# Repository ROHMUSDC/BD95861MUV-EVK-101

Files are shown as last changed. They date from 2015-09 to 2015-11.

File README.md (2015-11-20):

# BD95861MUV-EVK-101 Design Resource Repository
* Hardware Design Files and Documentation for the ROHM BD95861MUV-EVK-101 EVK

----
### Description: 
* BD95861MUV is a 1ch synchronous buck converter that can generate output voltage (0.8V to 5.5V) at the input voltage range (7.5V to 18V)
* Space-saving and high efficient switching regulator can be achieved due to built-in N-MOSFET power transistors
* The IC also incorporates H3 RegTM technology, a Rohm proprietary constant ON TIME control mode which facilitates ultra-high transient response against changes in load without external compensation components
* Fixed soft start function, power good function, and short circuit/over voltage protection with timer latch functions are incorporated
* The BD95861MUV is designed for power supplies for Digital AV Equipment

----
### Repository Contents
* Application Note Folder: Contains Draft Version of EVK Application Note
* Design Files: Contains Board, Gerber, Schematic, and BOM information for this EVK Board
* Measurement Reports Folder: Contains measurement testing information completed for these EVK Boards

----
### Where to Purchase?
* http://www.rohm.com/web/global/distribution/-/dinventory/BD95861MUV-EVK-101/sample/0

----
### DISCLAIMER
This Technical Data is protected under copyright laws.

ROHM hereby grants you a nonexclusive, nontransferable license to use this Technical Data 
as long as you abide by the terms and conditions of this DISCLAIMER. 

However, you are not authorized to sell, loan, rent, lease, redistribute or license this Technical Data, 
in whole or in part, or in modified form, to anyone.

You may modify this Technical Data to suit your specific applications, 
but the rights to derivative works and said modifications shall belong to ROHM. 

You may make copies of this Technical Data as necessary for internal use only within your company.

In any case, the latest datasheet is considered the final design guideline and represents 
the only actual performance specifications.

ROHM shall not be responsible for ensuring proper application on all computer systems.
This Technical Data is provided AS IS. ROHM makes no guarantees, either implicitly or explicitly, 
regarding its usability, functionality, accuracy, merchantability, or fitness for a specific purpose.

In addition, you shall take full responsibility for the use of any information acquired from this Technical Data. 

ROHM does not assume warranty of any kind arising from the use of this Technical Data. ACCORDINGLY, 
IN NO EVENT SHALL ROHM BE RESPONSIBLE, WHETHER THROUGH CONTRACT OR TORT LIABILITY, 
FOR ANY DAMAGES (INCLUDING BUT NOT LIMITED TO LOST PROFITS OR OTHER INCIDENTAL, CONSEQUENTAL, 
OR PUNITIVE DAMAGES) ARISING OUT OF OR IN CONNECTION WITH THE USE OR APPLICATION OF THIS Technical Data.

Furthermore, this Technical Data is subject to change without notice.

Unless otherwise expressly provided herein, ROHM does not convey any license under patent rights 
or any other intellectual property rights (including those of third parties).

ROHM is not obligated to provide maintenance or support for the Technical Data.

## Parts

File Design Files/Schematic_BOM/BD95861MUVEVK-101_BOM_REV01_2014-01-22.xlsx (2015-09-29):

ROHM - TITLE & REVISION HISTORY Revised: Tuesday, January 07, 2014
xxxx Revision: 01
Bill Of Materials January 7,2014 10:31:23 | Page1
Item | Quantity | Reference | Part | PCB Footprint | DESCRIPTION | MANUFACTURER1 | MANUFACTURER1_PART# | DISTR1 | DISTR1_PART# | DNP
______________________________________________
1 | 1 | CR1 | SML-310MTT86 | LED_0603 | LED 570NM GREEN WTR CLR 0603 SMD | Rohm | SML-310MTT86 | DIGIKEY | 511-1299-1-ND
2 | 2 | C1,C2 | 10uF | C1206 | CAP CER 10UF 25V 20% X5R 1206 | Murata | GRM31CR61E106MA12L | DIGIKEY | 490-5423-1-ND
3 | 1 | C3 | 0.1uF | C0603 | CAP CER 0.1UF 50V 10% X7R 0603 | Murata | GRM188R71H104KA93D | DIGIKEY | 490-1519-1-ND
4 | 2 | C4,C5 | 22uF | C1206 | CAP CER 22UF 16V 10% X5R 1206 | Murata | GRM31CR61C226KE15K | DIGIKEY | 490-6512-1-ND
5 | 1 | C6 | 4.7uF | C0603 | CAP CER 4.7UF 25V 10% X5R 0603 | Murata | GRM188R61E475KE11D | DIGIKEY | 490-7203-1-ND
6 | 1 | C7 | 0.47uF | C0603 | CAP CER 0.47UF 25V 10% X7R 0603 | Murata | GRM188R71E474KA12D | DIGIKEY | 490-3291-2-ND
7 | 1 | C8 |  | C1206 |  |  |  |  |  | DNP( Do not place)
8 | 1 | C9 |  | C0805 |  |  |  |  |  | DNP( Do not place)
9 | 1 | D1 | SMAJ15A | DO-214AC | DIODE TVS 15V 400W UNI 5% SMA | Littelfuse Inc | SMAJ15A | DIGIKEY | SMAJ15ALFTR-ND
10 | 2 | D2,D3 | RB085B-30TL | CPD | DIODE SCHOTTKY 30V 10A CPD | Rohm | RB085B-30TL | DIGIKEY | RB085B-30TLCT-ND | DNP( Do not place)
11 | 1 | J1 | 87224-3 | HDR_THVT_1X3_100 | CONN HEADER VERT .100 3POS 15AU | TE Connectivity Div | 87224-3 | DIGIKEY | A26545-ND
12 | 1 | L1 | 2.2uH | SMT_7P1X6P5 | INDUCTOR 2.2UH 8.2A 20% SMD | TDK Corporation | SPM6530T-2R2M | DIGIKEY | 445-4118-1-ND
13 | 1 | Q1 | SST2222AT116 | SOT23_BEC | TRANSISTOR NPN 40V 0.6A SOT-23 | Rohm | SST2222AT116 | DIGIKEY | SST2222AT116TR-ND
14 | 1 | R1 | 20 | R0603 | RES 20 OHM 1/10W 5% 0603 SMD | Rohm | MCR03ERTJ200 | DIGIKEY | RHM20CGTR-ND
15 | 1 | R2 | 24K | R0603 | RES 24K OHM 1/10W 1% 0603 SMD | Rohm | MCR03ERTF2402 | DIGIKEY | RHM24KCFDKR-ND
16 | 1 | R3 | 680 | R0603 | RES 680 OHM 1/10W 1% 0603 SMD | Rohm | MCR03ERTF6800 | DIGIKEY | RHM680CFTR-ND
17 | 1 | R4 | 4.7K | R0603 | RES 4.7K OHM 1/10W 1% 0603 SMD | Rohm | MCR03ERTF4701 | DIGIKEY | RHM4.70KCFTR-ND
18 | 1 | R5 | 100K | R0603 | RES 100K OHM 1/10W 5% 0603 SMD | Rohm | MCR03ERTJ104 | DIGIKEY | RHM100KCGTR-ND
19 | 1 | R6 | 1K | R0603 | RES 1K OHM 1/10W 5% 0603 SMD | Rohm | MCR03ERTJ102 | DIGIKEY | RHM1.0KCGTR-ND
20 | 1 | R7 | 140 | R0603 | RES 140 OHM 1/10W 1% 0603 SMD | Rohm | MCR03ERTF1400 | DIGIKEY | RHM140CFTR-ND
21 | 3 | TP1,TP2,TP5 | TP_63Mil_TH | TP_TH | TEST POINT PC MULTI PURPOSE RED | Keystone Electronics | 5010 | DIGIKEY | 5010K-ND
22 | 2 | TP3,TP4 | TP_63Mil_TH | TP_TH | TEST POINT PC MULTI PURPOSE BLK | Keystone Electronics | 5011 | DIGIKEY | 5011K-ND
23 | 1 | U1 | BD95861MUV | VQFN024V4040 | 7.5V to 18V, 6A Integrated MOSFET 1ch Synchronous Buck DC/DC Converter | ROHM | BD95861MUV
24 | 1 | ZX1 | 0 | SM_180x060 | 1806 footprint solder-short during assembly
25 | 1 |  |  |  | Shunt jumper for header J1 (item #11), CONN SHUNT 2POS GOLD W/HANDLE | TE Connectivity | 881545-1 | DIGIKEY | 881545-1-ND

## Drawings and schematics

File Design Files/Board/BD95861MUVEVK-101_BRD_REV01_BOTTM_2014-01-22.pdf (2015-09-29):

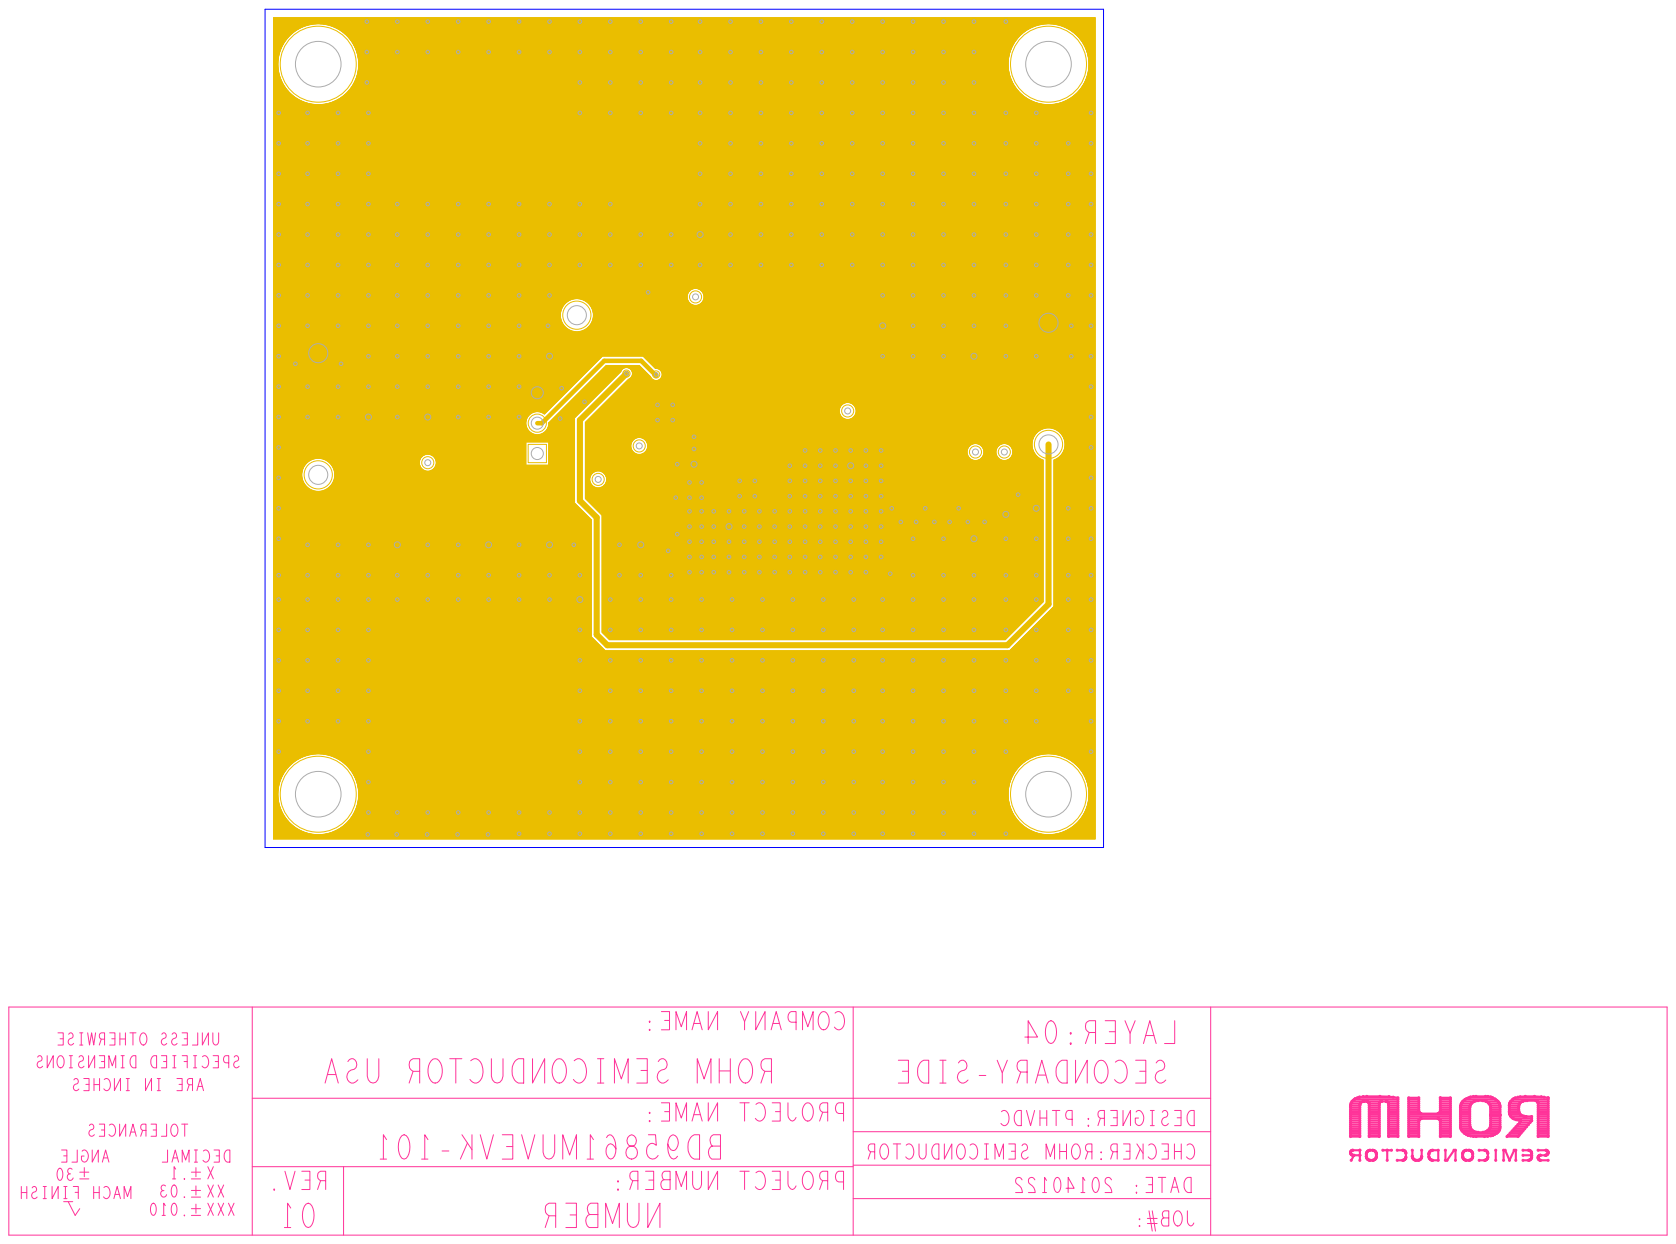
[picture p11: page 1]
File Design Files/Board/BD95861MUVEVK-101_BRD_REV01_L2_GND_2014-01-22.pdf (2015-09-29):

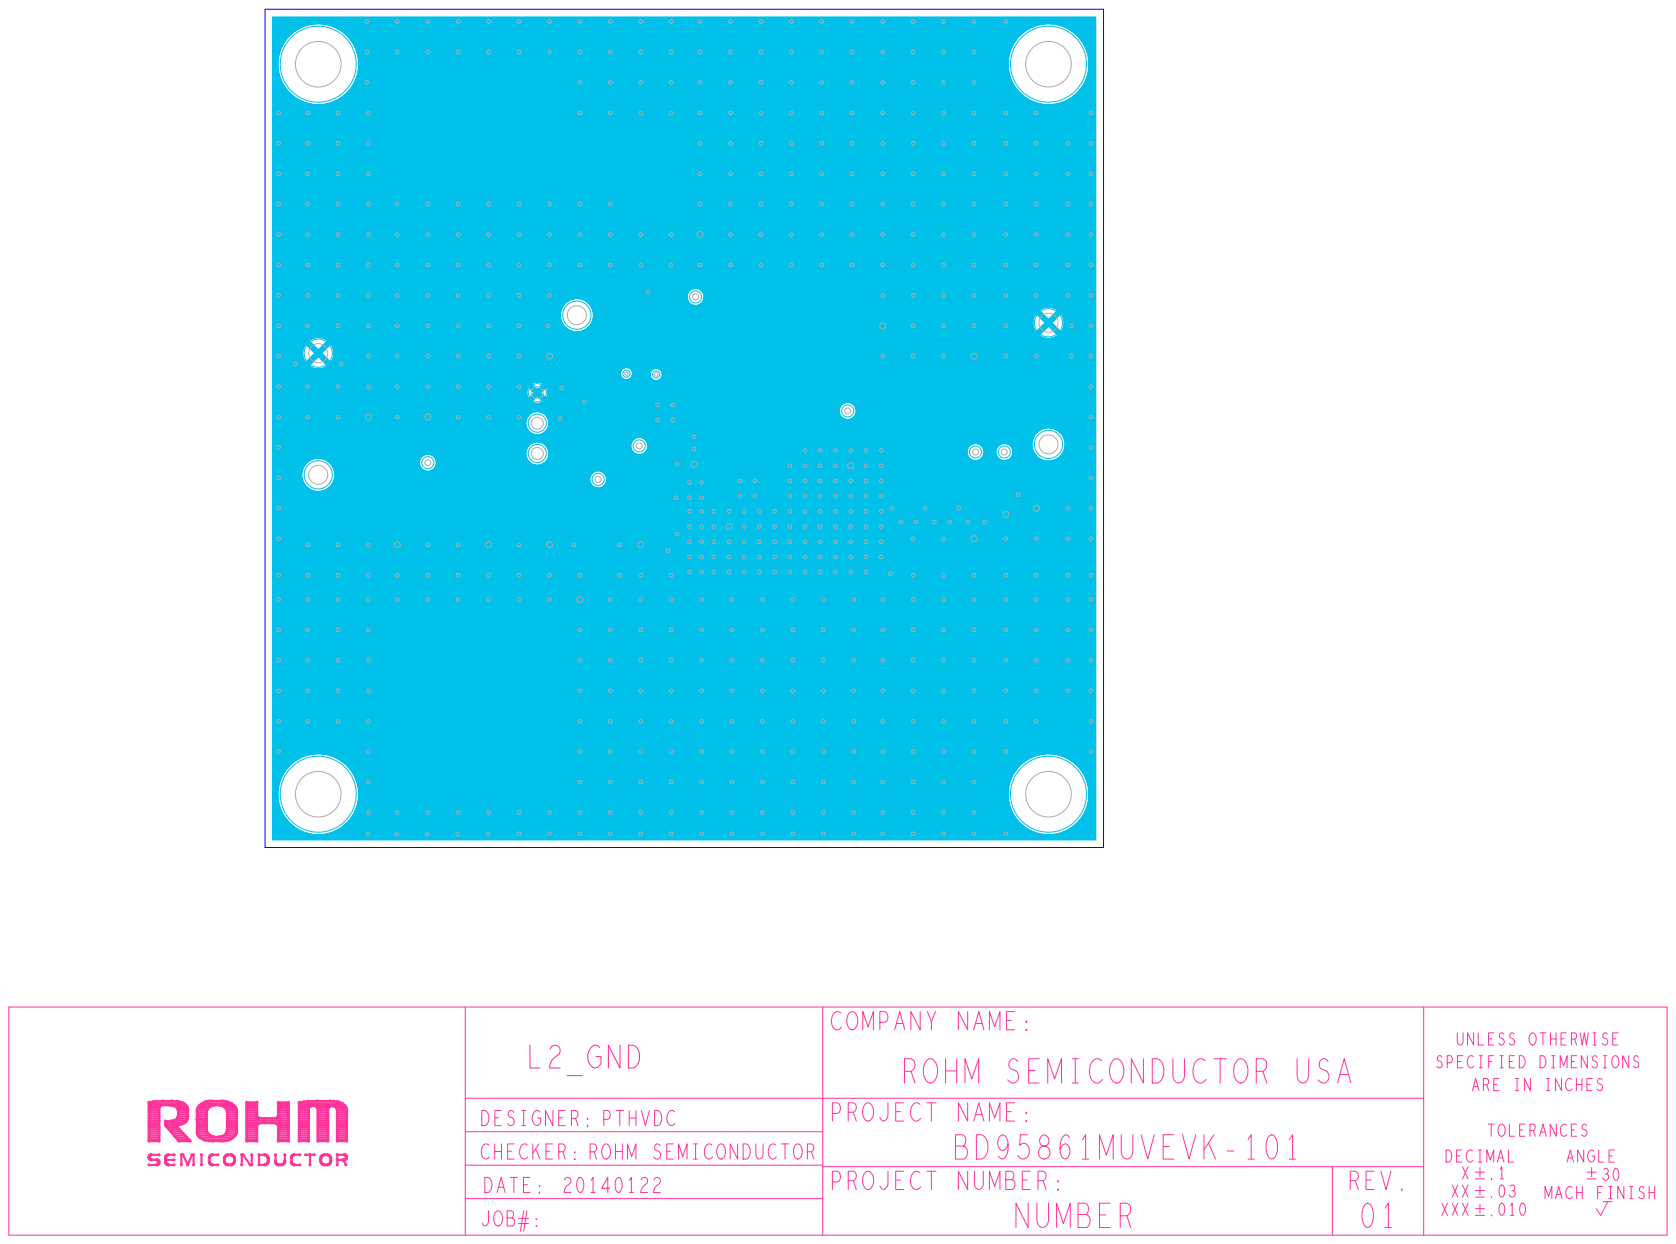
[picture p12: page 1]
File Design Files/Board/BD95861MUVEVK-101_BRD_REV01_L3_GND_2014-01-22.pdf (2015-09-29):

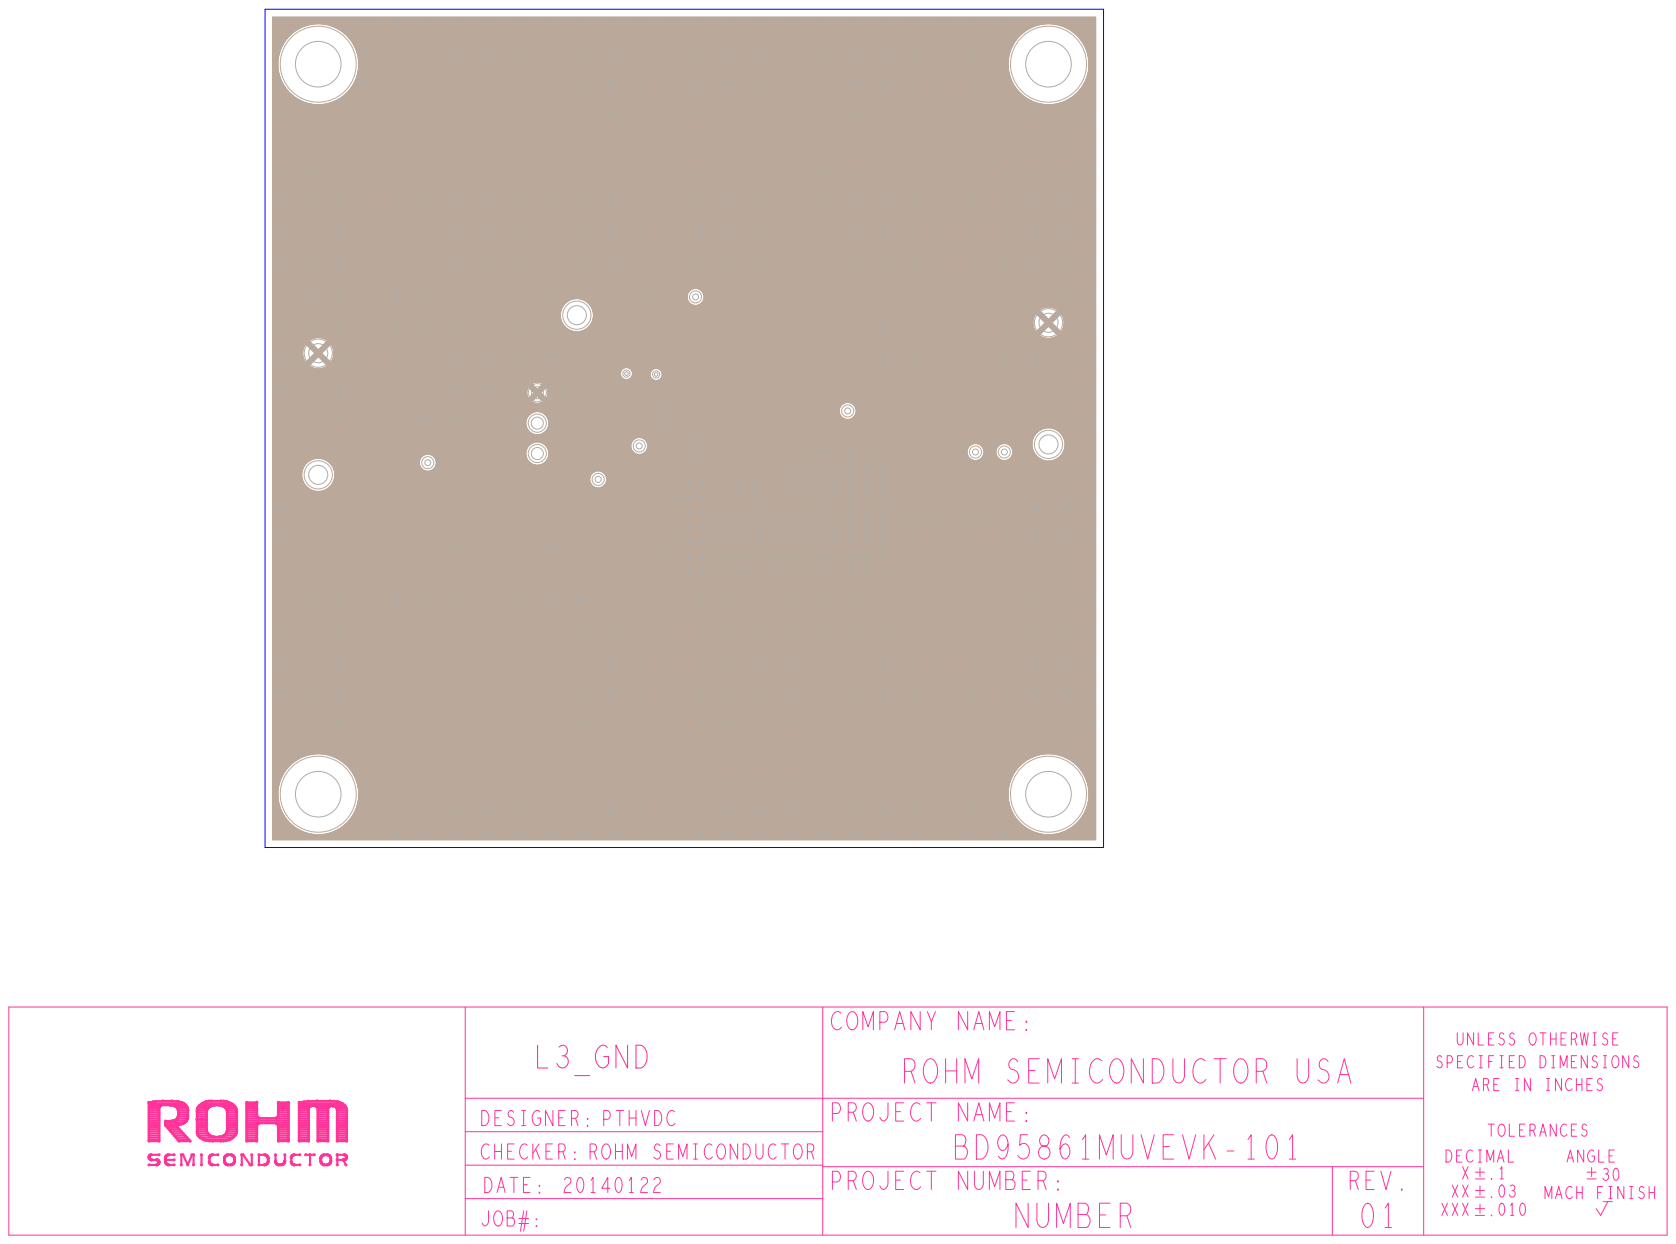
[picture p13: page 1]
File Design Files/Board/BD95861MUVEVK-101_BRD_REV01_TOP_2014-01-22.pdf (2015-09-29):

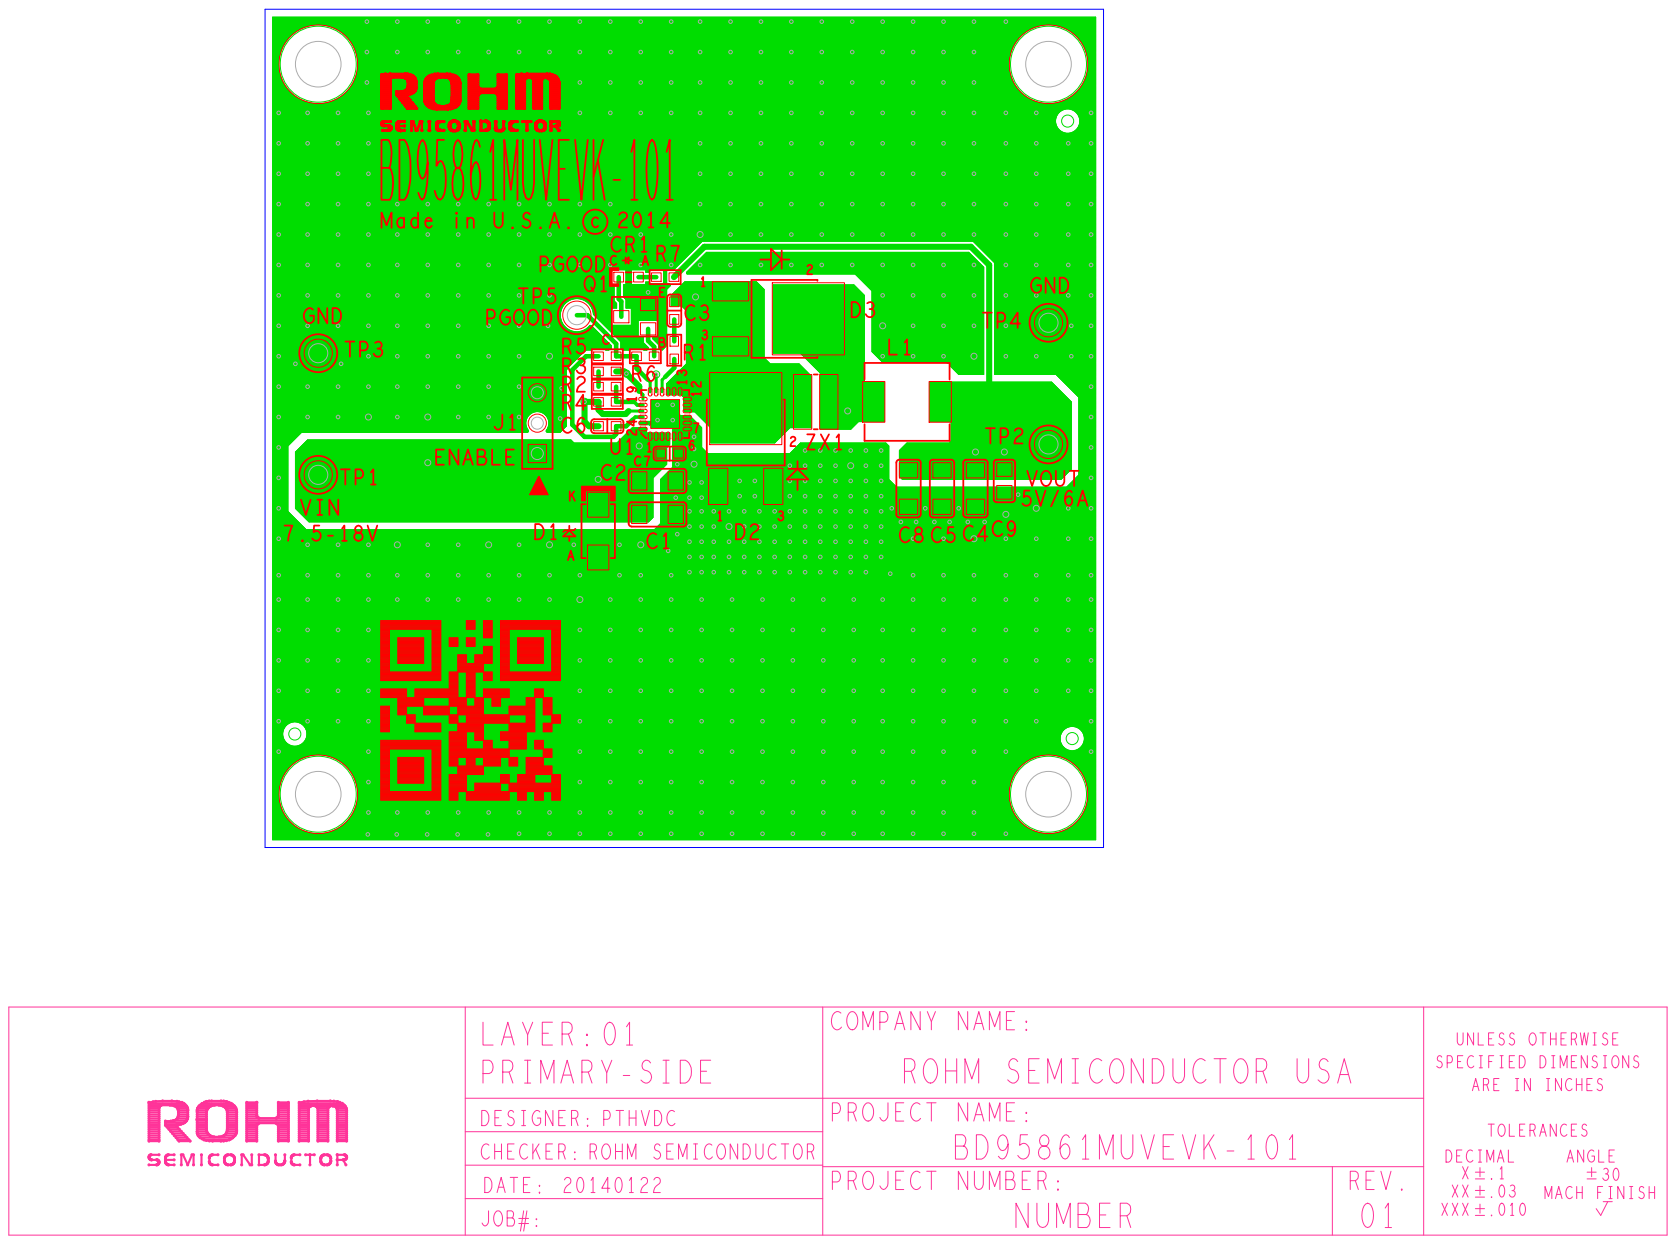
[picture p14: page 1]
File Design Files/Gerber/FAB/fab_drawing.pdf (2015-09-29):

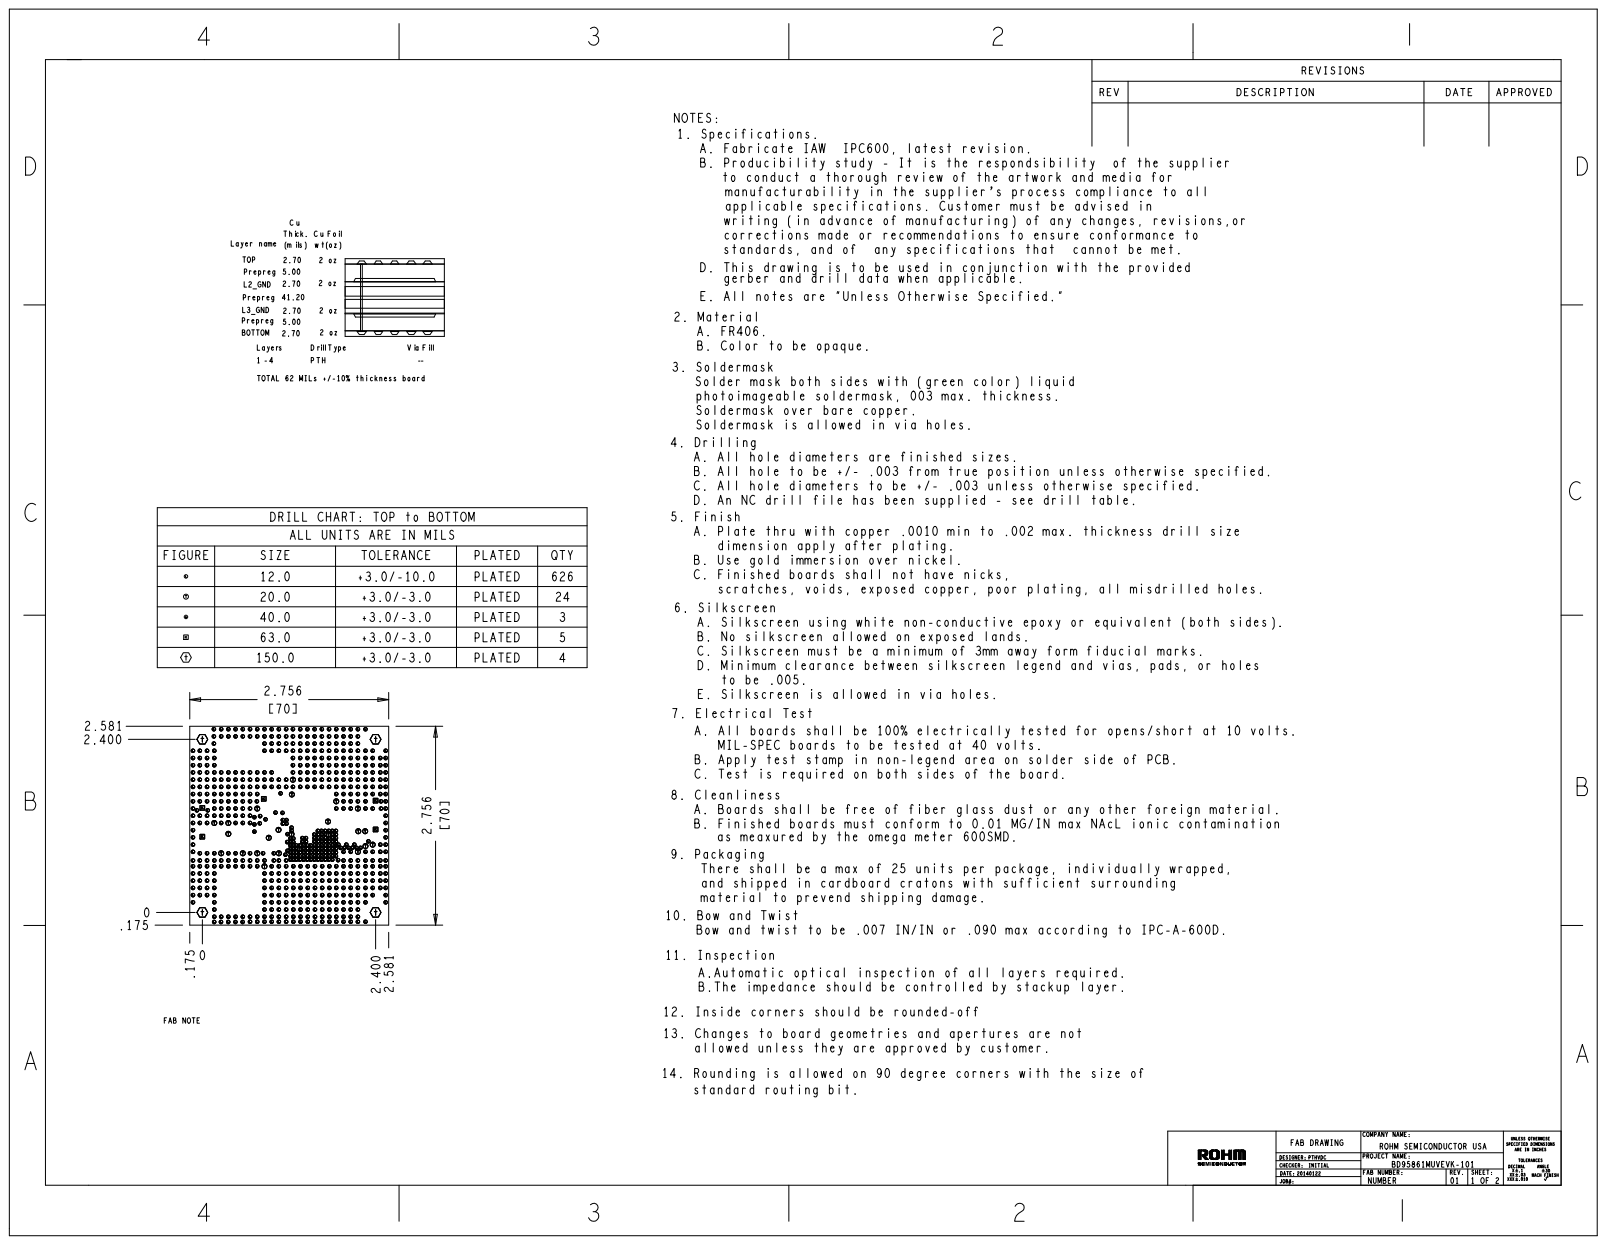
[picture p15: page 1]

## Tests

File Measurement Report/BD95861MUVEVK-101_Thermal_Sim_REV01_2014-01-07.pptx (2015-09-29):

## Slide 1

PI and Thermal Simulation Study for BD95861MUV Board
January 07th, 2014
Hosted by: Xuan Dang

PTH Solutions Confidential

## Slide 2

Agenda
  I. Introduction
  II. DC Drop Analysis
  III. Current Density Analysis
  IV. Thermal Analysis
  V. Conclusion

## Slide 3

Introduction

1. This work considers power simulation and thermal simulation on BD95861MUV boards.
  - Based on board file BD95861MUVEVK-101_EVAL_BRD_REV02_20140107_1800.brd
2. Hyperlynx v8.2.1 and Hyperlynx Thermal v9.1 (MentorGraphic) software is used for simulation
3. PI simulation considers:
  a. DC Drop analysis
    - Determine what the max drop for power rail
  b. Current Density analysis
    - Determine the hot spot of current density on PCB
4. Thermal simulation considers:
    - PCB temperature profile including consideration for conductive, radiative, and convective heat transfer

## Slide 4

BD95861MUV Board

- Based on the board file : BD95861MUVEVK-101_EVAL_BRD_REV02_20140107_1800.brd

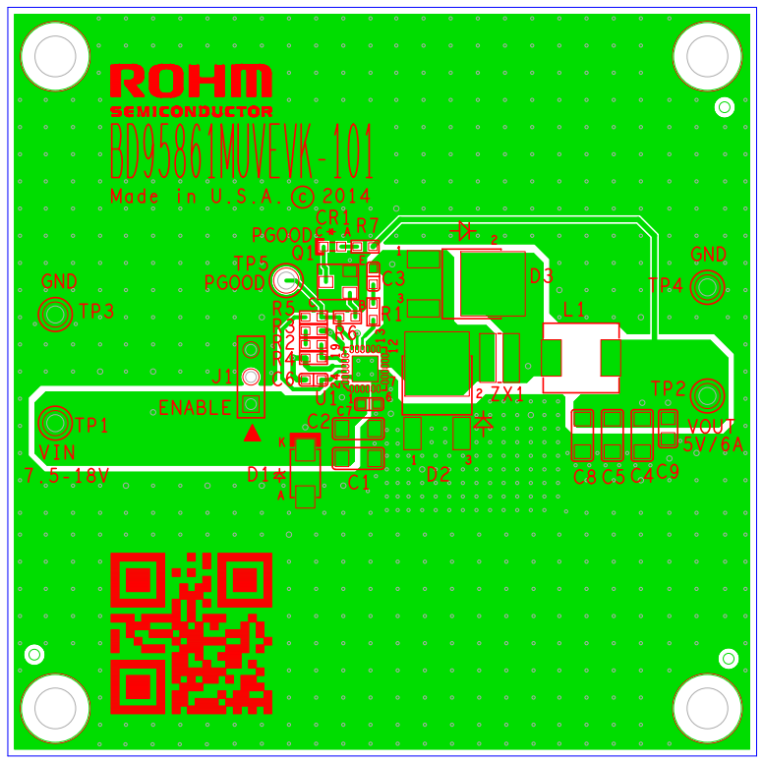
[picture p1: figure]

Vin 5V/div (DC)

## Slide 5

BD95861MUV Schematic

Based on the schematic file : BD95861MUV_EVAL_SCH_REV02_20140107_1800.pdf

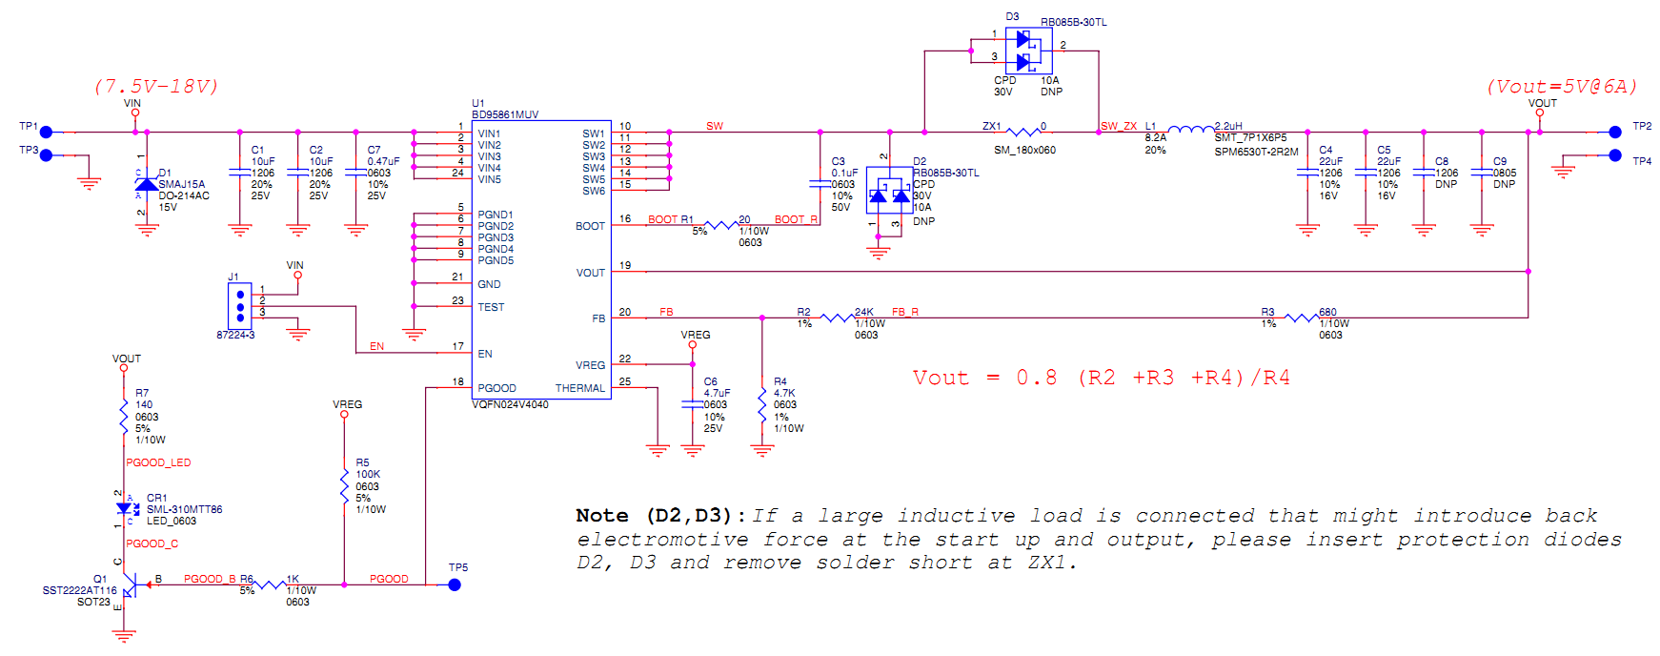
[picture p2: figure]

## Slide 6

BD95861MUV Board power consumption

Device/rail | Source/VRM refdes | Source PCB netname | Sink/load PCB refdes | Load PCB net name | Nominal Voltage(V) | Voltage tolerance (%) | Max current (A) | Power input (W) | Power consumption (W) | Note
Power input via TP1/TP3 connectors (VIN 7.5-18V) | TP1 | VIN | U1 | VIN | 7.50 | | 5.00 | 37.50 | | Max input current = (Pout + PONH + PONL + PL)/VIN = 4.44A with Vin =7.5V (worst condition). So we choose max input current =5A to simulate power/thermal
Power dissipation on BD95861MUV internal FETs | TP1 | VIN | U1 | VIN | | | 6.00 | | 3.12 | RONH=0.1 Ohm; RONL=0.06 Ohm
Power dissipation on inductor L1 | ZX1 | SW | L1 | SW_ZX | | | 6.00 | | 0.68 | RL = 0.019 Ohm
Power consumption at load via connector TP2/TP4 (VOUT 5V) | L1 | VOUT | TP2 | VOUT | 5 | 2 | 6.00 | | 30.00
| | | | | | | Total | 37.50 | 33.80

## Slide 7

Current Density analysis for VIN7.5V@5A

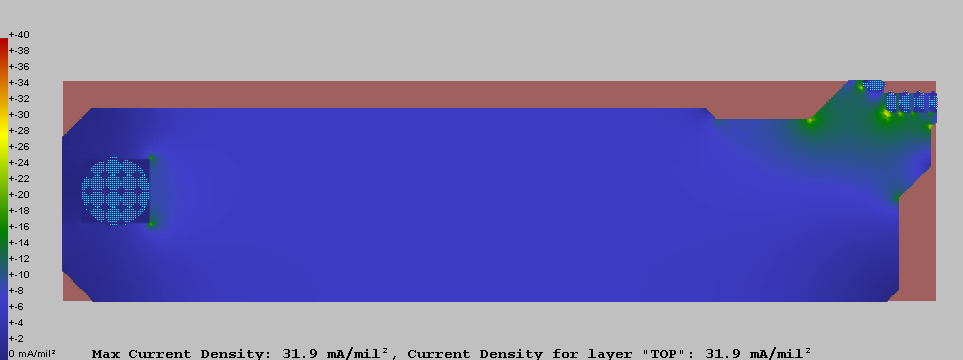
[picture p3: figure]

Max Current Density 31.9mA/mil² < 40mA/mil² (This rule limit 10 ⁰C of temperature rise above ambient) → Copper planes for VIN is OK

Source TP1

Load U1

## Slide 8

DC Drop analysis for VIN7.5V@5A

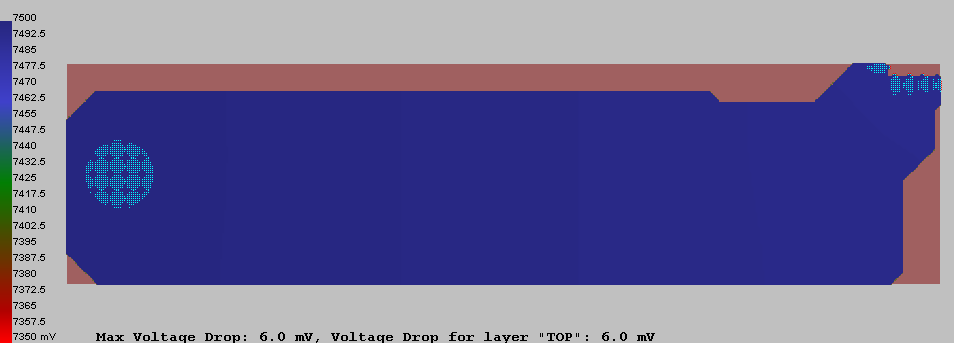
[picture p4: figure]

Max DC Drop 6.0mV < 150mV (2% tolerance of 7.5V) → Copper planes for VIN is OK

Source TP1

Load U1

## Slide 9

Current Density analysis for SW@6A

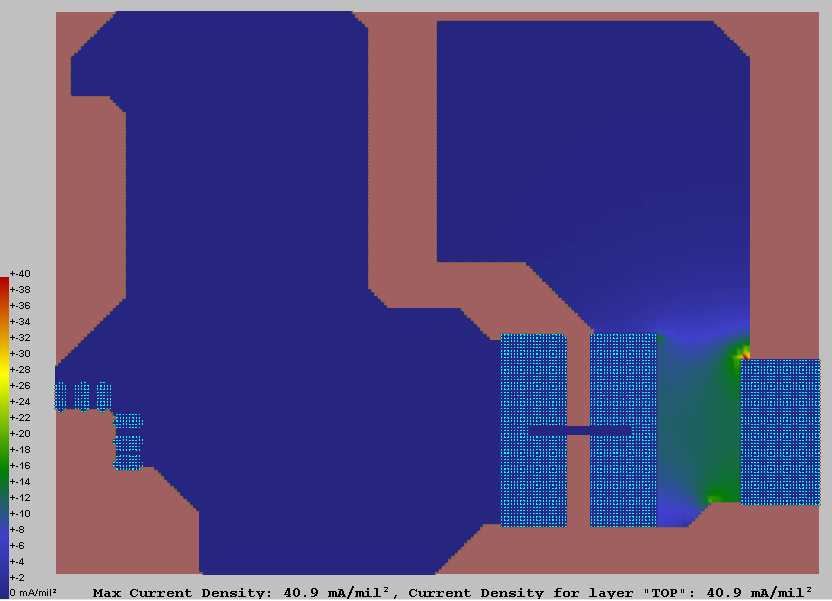
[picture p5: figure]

Source U1

Solder-shorted ZX1

Load L1

Max Current Density 40.9mA/mil² ~ 40mA/mil² (This rule limit 10 ⁰C of temperature rise above ambient) → Copper plane for SW is OK

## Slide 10

DC Drop analysis for SW@6A

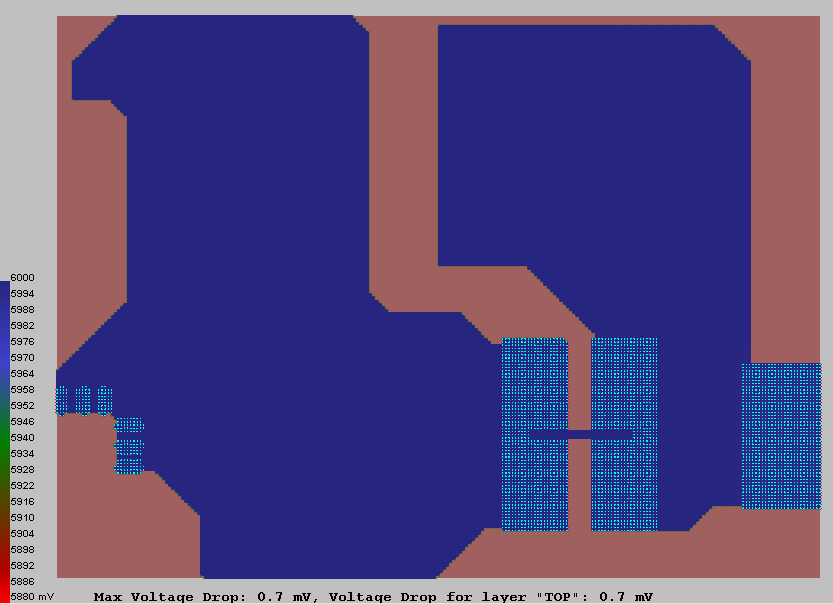
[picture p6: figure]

Max DC Drop 0.7 mV < 120mV (2% tolerance of assumption voltage 6V) → Copper planes for SW is OK

Source U1

Solder-shorted ZX1

Load L1

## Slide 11

Current Density analysis for VOUT 5V@6A

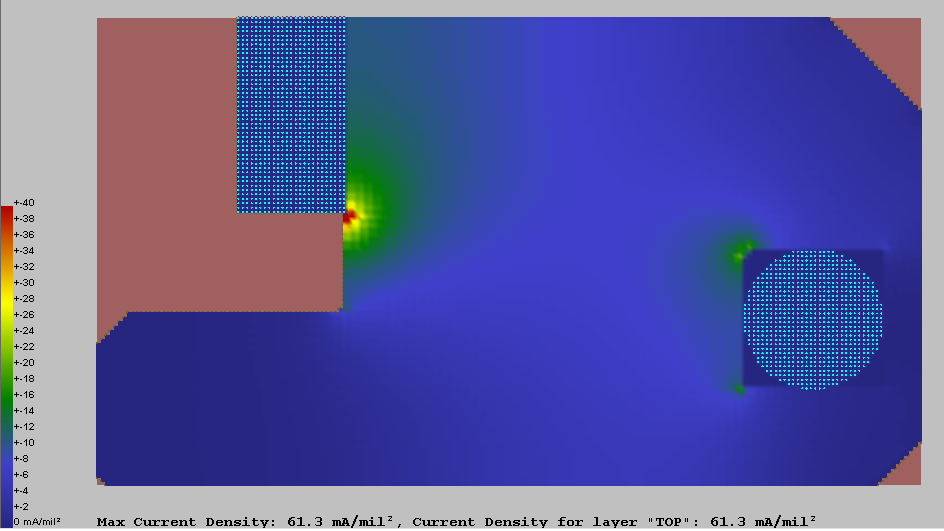
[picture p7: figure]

Max Current Density 61.3mA/mil² > 40mA/mil² (This rule limit 10 ⁰C of temperature rise above ambient) → We reduced VOUT’s current density as possible

Source L1

Load TP2

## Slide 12

DC Drop analysis for VOUT 5V@6A

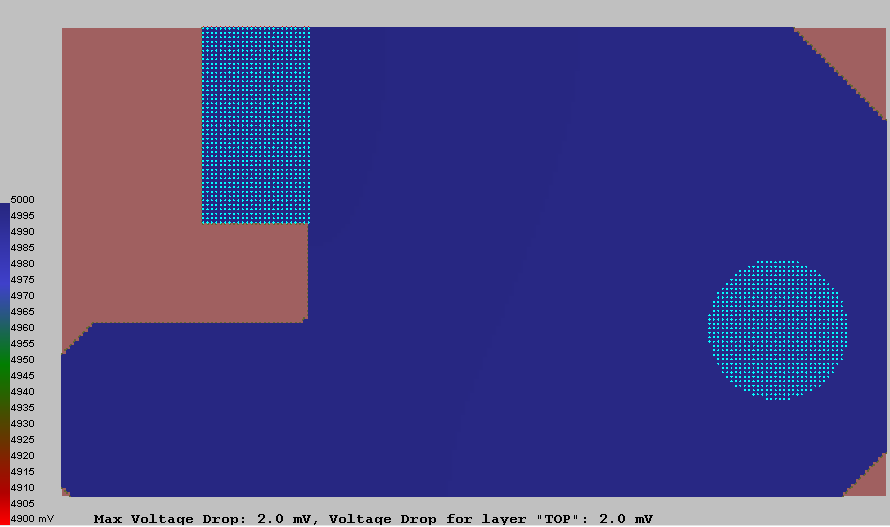
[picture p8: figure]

Max DC Drop 2.0 mV < 100mV (2% tolerance of 5V) → Copper planes for VOUT is OK

Source L1

Load TP2

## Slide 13

Thermal Analysis

a. Environment conditions
  a. Air Temperature : 25 ⁰C , 35 ⁰C and 45 ⁰C
  b. Air Pressure: 1 atm
  c. Gravity: 1
  d. Humidity ratio: 0.5%
  e. No incoming air flow (Natural convection)
  f. Emissivity of board: 1
  g. Board location : single board
  h. System: closed

SW 5V/div

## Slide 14

Thermal Analysis (Con’t)

b. Component properties

| BD96861MUV | SPM6530T-2R2M | RB085B-30TL (Diode D3) | SML-310MTT86 | SST2222AT116
Number of pins | 25 | 2 | 3 | 2 | 3
Pin length | 0.028” | 0.134” | 0.063 | 0.032 | 0.05
Pin width | 0.012” | 0.073” | 0.019 | 0.032 | 0.04
Pin thickness | 0.009” | 0.006 | 0.02 | 0.01 | 0.005
Pin thermal conductivity | 223.031Btu/hrftF | 223.031Btu/hrftF | 223.031Btu/hrftF | 223.031Btu/hrftF | 223.031Btu/hrftF
Max. power dissipation | 3.12 W (at Vin=7.5V) 2.76W (at Vin=12V) | 0.684 W | 2.88 W | 0.044 W | 0.012 W

VOUT 20mV/div (AC)

SW 5V/div

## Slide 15

Thermal Analysis (Con’t)

Air temperature 25⁰C, power dissipation of BD95861MUV is 3.12W (at VIN=7.5V), exclude power dissipation of DNP diode D3 RB085B-30TL

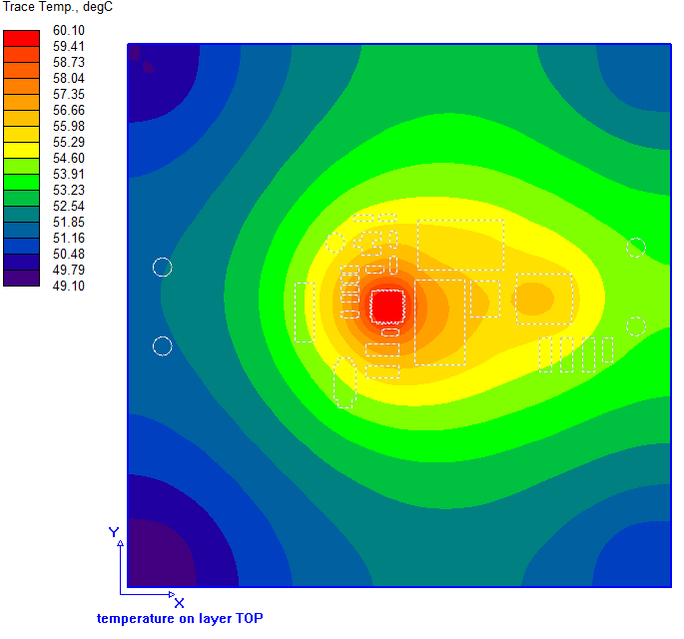
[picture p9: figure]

The highest temperature on board is about 60.1 ⁰C
The highest temperature on component is on BD95861MUV ( about 70 ⁰C)

U1: BD95861MUV
- Max. power dissipation: 3.12 W @VIN=7.5V
- Component temperature = 70 ⁰C

L1: SPM6530T-2R2M
- Max. power dissipation: 0.684 W
- Component temperature = 56.7 ⁰C

D3:RB085B-30TL
- Component temperature = 55.5 ⁰C

U1

D3

L1

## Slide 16

Thermal Analysis (Con’t)

Air temperature 35⁰C, power dissipation of BD95861MUV is 3.12W (at VIN=7.5V), exclude power dissipation of DNP diode D3 RB085B-30TL

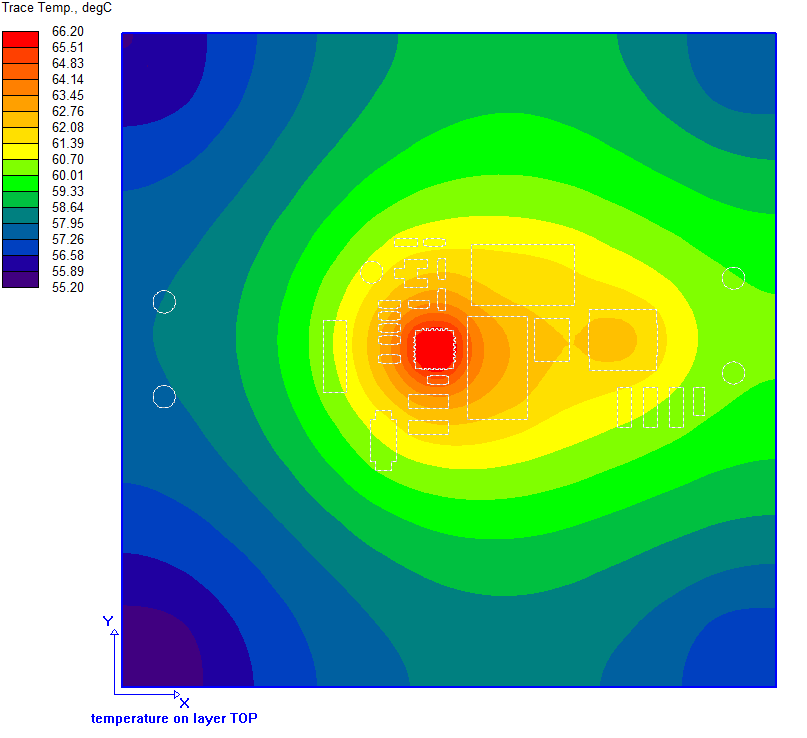
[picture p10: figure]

The highest temperature on board is about 66.2 ⁰C
The highest temperature on component is on BD95861MUV ( about 76.2 ⁰C)

U1: BD95861MUV
- Max. power dissipation: 3.12 W @VIN=7.5V
- Component temperature = 76.2 ⁰C

L1: SPM6530T-2R2M
- Max. power dissipation: 0.684 W
- Component temperature = 62.8 ⁰C

D3:RB085B-30TL
- Component temperature = 61.7 ⁰C

U1

D3

L1

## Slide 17

Thermal Analysis (Con’t)

Air temperature 45⁰C, power dissipation of BD95861MUV is 3.12W (at VIN=7.5V), exclude power dissipation of DNP diode D3 RB085B-30TL


The highest temperature on board is about 72.4 ⁰C
The highest temperature on component is on BD95861MUV ( about 82.4 ⁰C)

U1: BD95861MUV
- Max. power dissipation: 3.12 W @VIN=7.5V
- Component temperature = 82.4 ⁰C

L1: SPM6530T-2R2M
- Max. power dissipation: 0.684 W
- Component temperature = 69 ⁰C

D3:RB085B-30TL
- Component temperature = 67.9 ⁰C

U1

D3

L1

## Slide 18

Thermal Analysis (Con’t)

Air temperature 25⁰C, power dissipation of BD95861MUV is 3.12W (at VIN=7.5V), include power dissipation of DNP diode D3 RB085B-30TL


The highest temperature on board is about 89.2 ⁰C
The highest temperature on component is on BD95861MUV ( about 98.9 ⁰C)

U1: BD95861MUV
- Max. power dissipation: 3.12 W @VIN=7.5V
- Component temperature = 98.9 ⁰C

L1: SPM6530T-2R2M
- Max. power dissipation: 0.684 W
- Component temperature = 86.2 ⁰C

D3:RB085B-30TL
- Max. power dissipation: 2.88 W
- Component temperature = 90.3 ⁰C

U1

D3

L1

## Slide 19

Thermal Analysis (Con’t)

Air temperature 35⁰C, power dissipation of BD95861MUV is 3.12W (at VIN=7.5V), include power dissipation of DNP diode D3 RB085B-30TL


The highest temperature on board is about 94.9 ⁰C
The highest temperature on component is on BD95861MUV ( about 104.7 ⁰C)

U1: BD95861MUV
- Max. power dissipation: 3.12 W @VIN=7.5V
- Component temperature = 104.7 ⁰C

L1: SPM6530T-2R2M
- Max. power dissipation: 0.684 W
- Component temperature = 91.9 ⁰C

D3:RB085B-30TL
- Max. power dissipation: 2.88 W
- Component temperature = 96 ⁰C

U1

D3

L1

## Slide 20

Thermal Analysis (Con’t)

Air temperature 45⁰C, power dissipation of BD95861MUV is 3.12W (at VIN=7.5V), include power dissipation of DNP diode D3 RB085B-30TL


The highest temperature on board is about 100 ⁰C
The highest temperature on component is on BD95861MUV ( about 110.3 ⁰C)

U1: BD95861MUV
- Max. power dissipation: 3.12 W @VIN=7.5V
- Component temperature = 110.3 ⁰C

L1: SPM6530T-2R2M
- Max. power dissipation: 0.684 W
- Component temperature = 97.6 ⁰C

D3:RB085B-30TL
- Max. power dissipation: 2.88 W
- Component temperature = 101.7 ⁰C

U1

D3

L1

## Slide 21

Thermal Analysis (Con’t)

Air temperature 25⁰C, power dissipation of BD95861MUV is 2.76 W (at VIN=12V), exclude power dissipation of DNP diode D3 RB085B-30TL


The highest temperature on board is about 56 ⁰C
The highest temperature on component is on BD95861MUV ( about 64.8 ⁰C)

U1: BD95861MUV
- Max. power dissipation: 2.76 W @VIN=12V
- Component temperature = 64.8 ⁰C

L1: SPM6530T-2R2M
- Max. power dissipation: 0.684 W
- Component temperature = 53.3 ⁰C

D3:RB085B-30TL
- Component temperature = 52 ⁰C

U1

D3

L1

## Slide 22

Thermal Analysis (Con’t)

Air temperature 35⁰C, power dissipation of BD95861MUV is 2.76 W (at VIN=12V), exclude power dissipation of DNP diode D3 RB085B-30TL


The highest temperature on board is about 62.2 ⁰C
The highest temperature on component is on BD95861MUV ( about 71 ⁰C)

U1: BD95861MUV
- Max. power dissipation: 2.76 W @VIN=12V
- Component temperature = 71 ⁰C

L1: SPM6530T-2R2M
- Max. power dissipation: 0.684 W
- Component temperature = 59.5 ⁰C

D3:RB085B-30TL
- Component temperature = 58.2 ⁰C

U1

D3

L1

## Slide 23

Thermal Analysis (Con’t)

Air temperature 45⁰C, power dissipation of BD95861MUV is 2.76 W (at VIN=12V), exclude power dissipation of DNP diode D3 RB085B-30TL


The highest temperature on board is about 68.5 ⁰C
The highest temperature on component is on BD95861MUV ( about 77.3 ⁰C)

U1: BD95861MUV
- Max. power dissipation: 2.76 W @VIN=12V
- Component temperature = 77.3 ⁰C

L1: SPM6530T-2R2M
- Max. power dissipation: 0.684 W
- Component temperature = 65.8 ⁰C

D3:RB085B-30TL
- Component temperature = 64.5 ⁰C

U1

D3

L1

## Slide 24

Thermal Analysis (Con’t)

Air temperature 25⁰C, power dissipation of BD95861MUV is 2.76 W (at VIN=12V), include power dissipation of DNP diode D3 RB085B-30TL


The highest temperature on board is about 85.8 ⁰C
The highest temperature on component is on BD95861MUV ( about 94.1 ⁰C)

U1: BD95861MUV
- Max. power dissipation: 2.76 W @VIN=12V
- Component temperature = 94.1 ⁰C

L1: SPM6530T-2R2M
- Max. power dissipation: 0.684 W
- Component temperature = 83.2 ⁰C

D3:RB085B-30TL
- Max. power dissipation: 2.88 W
- Component temperature = 87.2 ⁰C

U1

D3

L1

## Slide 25

Thermal Analysis (Con’t)

Air temperature 35⁰C, power dissipation of BD95861MUV is 2.76 W (at VIN=12V), include power dissipation of DNP diode D3 RB085B-30TL


The highest temperature on board is about 91.5 ⁰C
The highest temperature on component is on BD95861MUV ( about 99.8 ⁰C)

U1: BD95861MUV
- Max. power dissipation: 2.76 W @VIN=12V
- Component temperature = 99.8 ⁰C

L1: SPM6530T-2R2M
- Max. power dissipation: 0.684 W
- Component temperature = 88.9 ⁰C

D3:RB085B-30TL
- Max. power dissipation: 2.88 W
- Component temperature = 92.9 ⁰C

U1

D3

L1

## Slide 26

Thermal Analysis (Con’t)

Air temperature 45⁰C, power dissipation of BD95861MUV is 2.76 W (at VIN=12V), include power dissipation of DNP diode D3 RB085B-30TL


U1: BD95861MUV
- Max. power dissipation: 2.76 W @VIN=12V
- Component temperature = 105.6 ⁰C

L1: SPM6530T-2R2M
- Max. power dissipation: 0.684 W
- Component temperature = 94.7 ⁰C

D3:RB085B-30TL
- Max. power dissipation: 2.88 W
- Component temperature = 98.7 ⁰C

U1

D3

L1

The highest temperature on board is about 97.3 ⁰C
The highest temperature on component is on BD95861MUV ( about 105.6 ⁰C)

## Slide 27

Summary

1. The PI simulation shows that the max. amount voltage drop of VIN power is 6.0mV, the max. current density of VIN power is 31.9mA/mil²; the max. amount voltage drop of SW power is 0.7mV, the max. current density of SW power is 40.9mA/mil²; the max. amount voltage drop of VOUT power is 2.0mV, the max. current density of VOUT power is 61.3mA/mil²
2. The highest temperature of BD95861MUV can be reached temperature as table below:

| VIN=7.5V | | VIN=12V
| D2, D3: not install | D2, D3: install | D2, D3: not install | D2, D3: install
Air temperature: 25⁰C | 70 ⁰C | 98.9 ⁰C | 64.8 ⁰C | 94.1 ⁰C
Air temperature: 35⁰C | 76.2 ⁰C | 104.7 ⁰C | 71 ⁰C | 99.8 ⁰C
Air temperature: 45⁰C | 82.4 ⁰C | 110.3 ⁰C | 77.3 ⁰C | 105.6 ⁰C
